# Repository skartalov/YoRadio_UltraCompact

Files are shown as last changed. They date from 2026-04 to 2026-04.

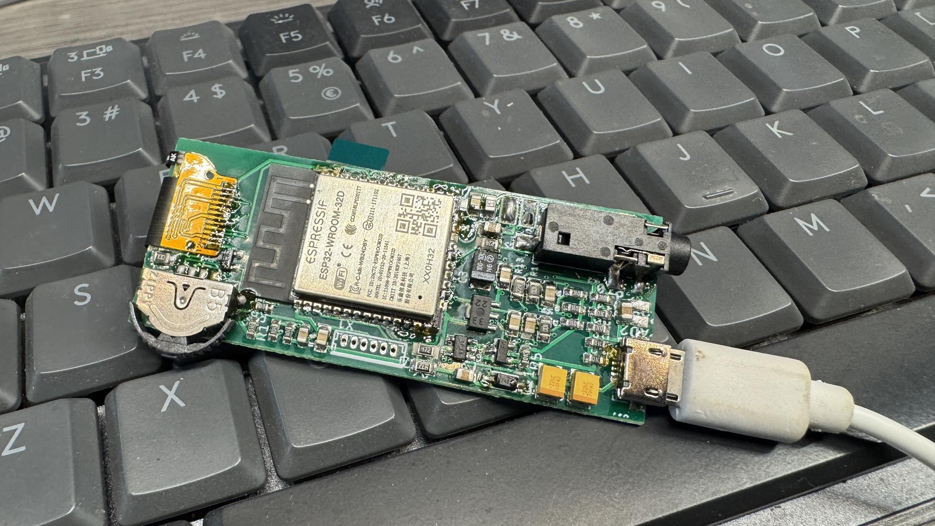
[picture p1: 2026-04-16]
674242527_10164483020409432_1686552852439329188_n.jpg

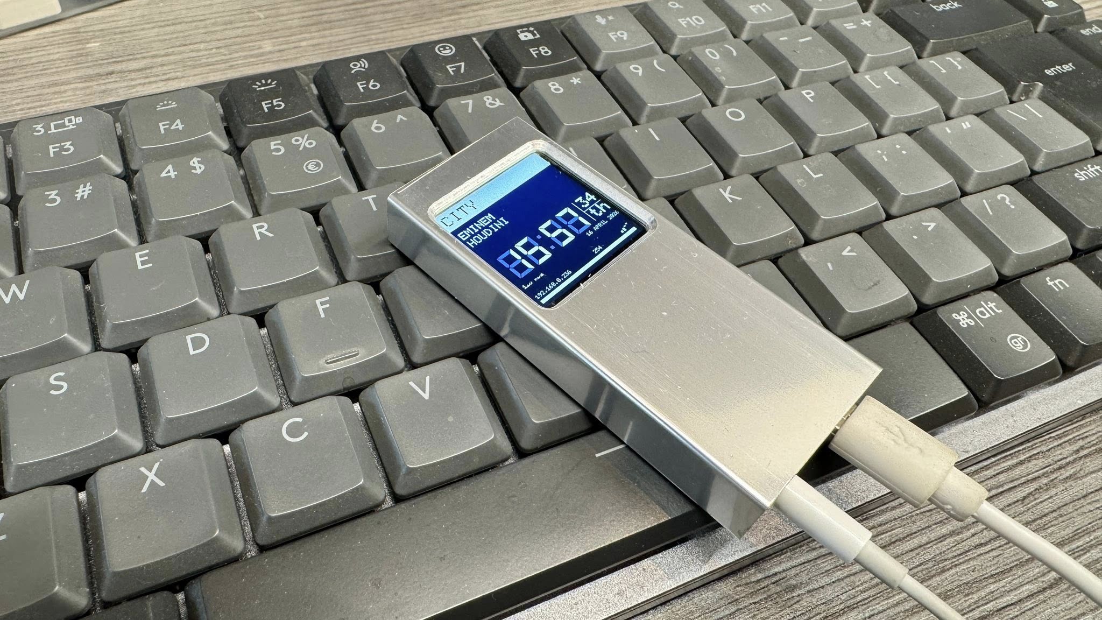
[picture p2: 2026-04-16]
670423982_10164483007904432_1156673706397125330_n.jpg

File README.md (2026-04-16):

This is custom project for YoRadio using 240x240 display, UDA1334 I2S stereo DAC, Li-Po battery charger, 3 way slide button.

Open the schematic and the board with EaglePCB.

Included are: myoptions.h for this specific board and some nice internet radios in playlist.csv

Use this on your own risk, no any support is included. Please don't ask questions. If you know what you are doing you will be able to build this project by your own. If you have questions - this project is not for you.

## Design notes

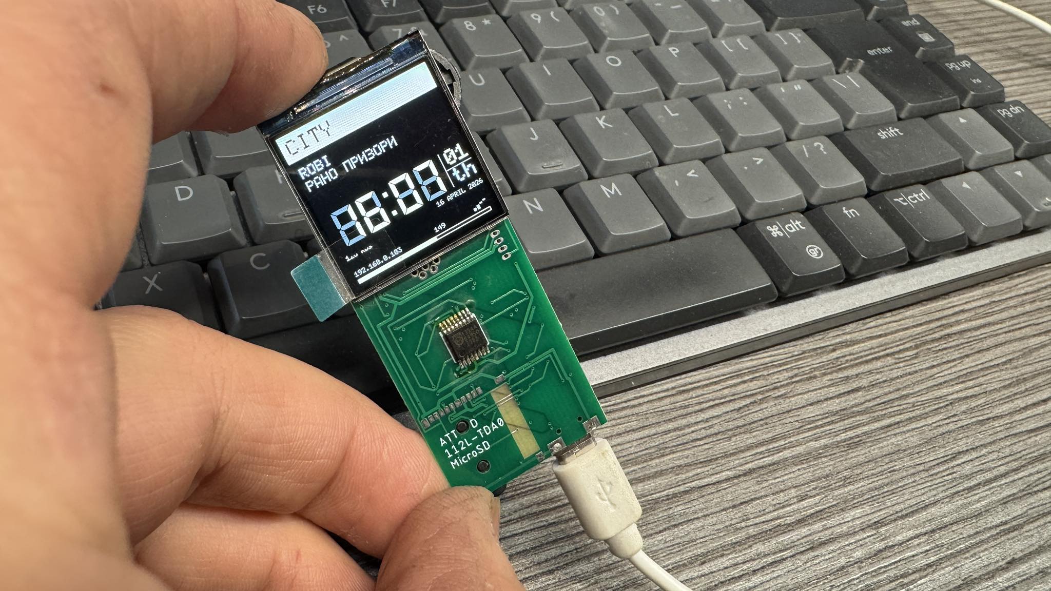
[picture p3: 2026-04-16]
673046234_10164483020429432_1007619045158390353_n.jpg

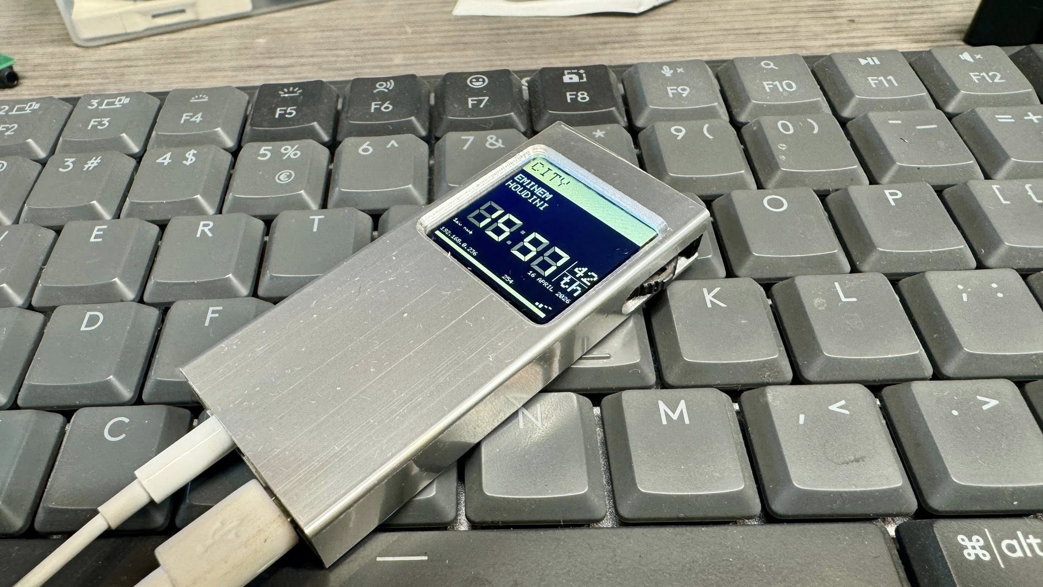
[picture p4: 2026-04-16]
670492199_10164483007809432_5799651930195477875_n.jpg

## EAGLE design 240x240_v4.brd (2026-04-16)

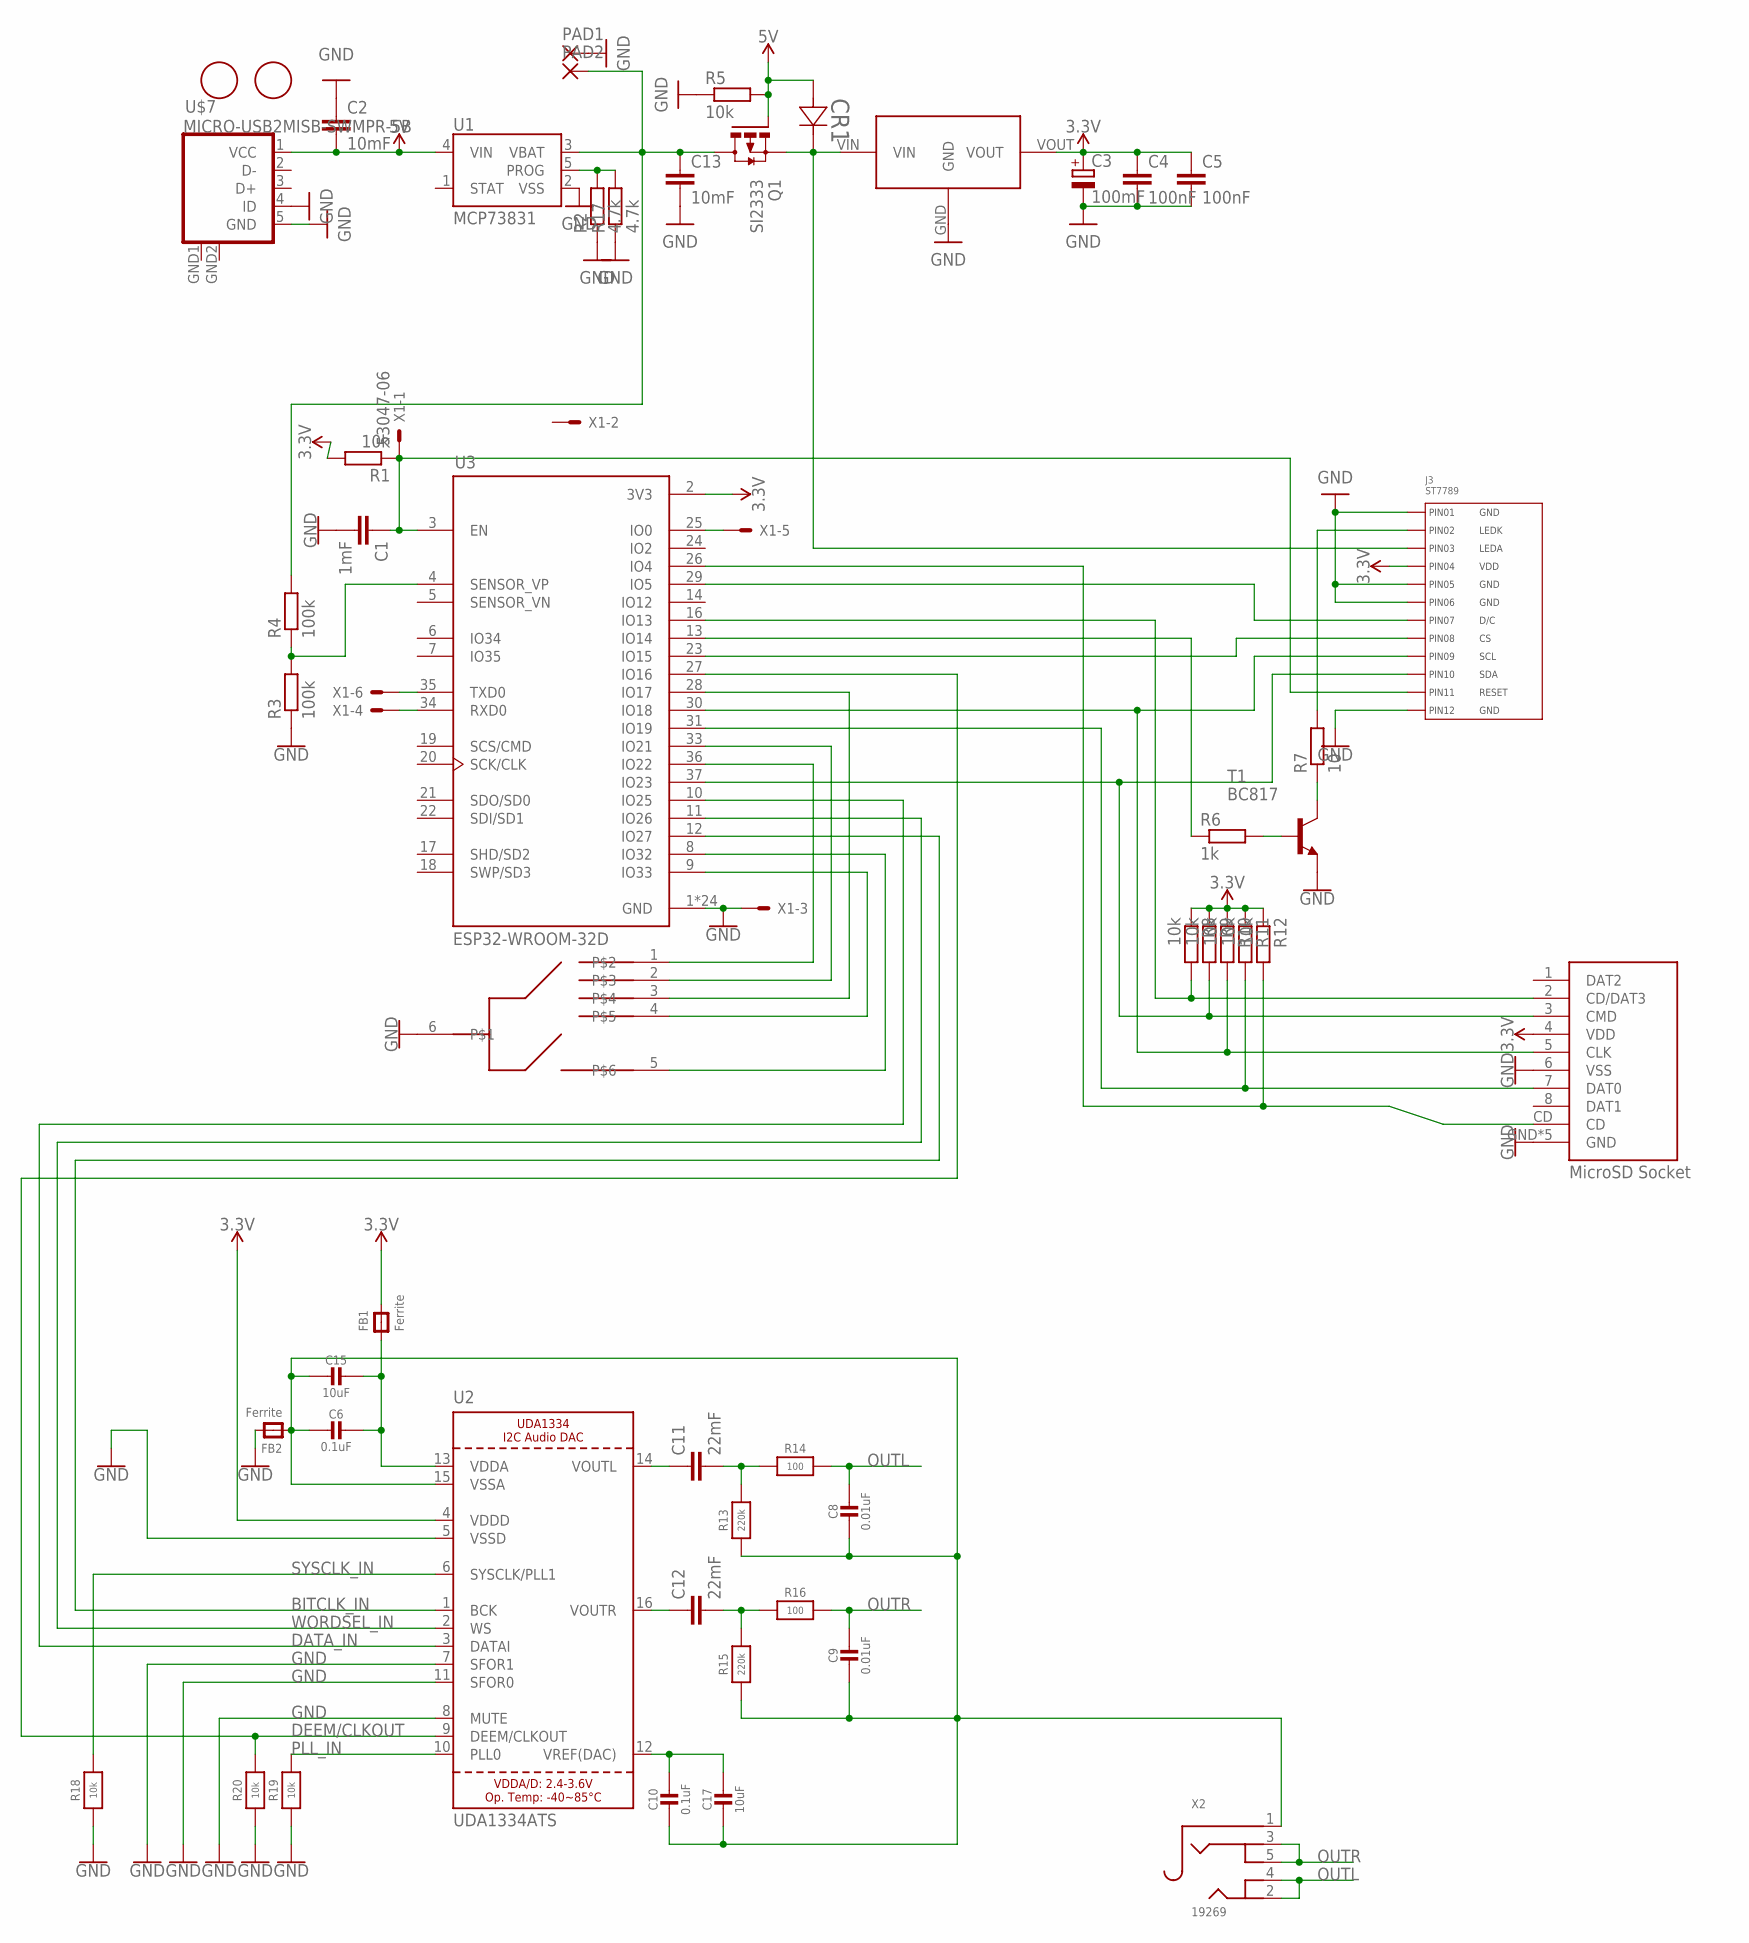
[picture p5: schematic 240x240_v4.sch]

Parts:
C1: 1mF; C0603
C2, C13: 10mF; C0603
C3: 100mF; SMC_B
C4, C5: 100nF; C0805K
C6, C10: 0.1uF; 0805-NO
C8, C9: 0.01uF; 0805-NO
C11, C12: 22mF; C1210
C15, C17: 10uF; 0805-NO
CR1: BAT48; SOD-123_STM-M
FB1, FB2: Ferrite; 0805
J3: ST7789; ST7789_CONNECTOR
PAD1, PAD2: SMD2; SMD1,27-2,54
Q1: SI2333; SUPER-SOT3
R1, R5, R8, R9, R10, R11, R12: 10k; R0603
R2, R17: 4.7k; R0805
R3, R4: 100k; R0603
R6: 1k; R0603
R7: 10; R0805
R13, R15: 220k; 0805-NO
R14, R16: 100; 0805-NO
R18, R19, R20: 10k; 0603-NO
T1: BC817; SOT23-BEC
U1: MCP73831; SOT23-5
U2: UDA1334ATS; SSOP16_4.4MM
U3: ESP32-WROOM-32D; MODULE_ESP32-WROOM-32D
U$1: XC6203; SOT89
U$2: B5-P5S-0D; B5-P5S-0D-Z
U$3, U$4: FIDUCIAL; FIDUCIAL_1MM
U$5: ATTEND_MICROSD_SOCKET
U$7: MICRO-USB2MISB-SWMPR-5B; MICRO-USB2
X1: 53047-06
X2: 19269; 4UCONN_19269

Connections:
3.3V: C3.+, C4.1, C5.1, FB1.2, J3.P$4 (4), R1.2, R8.1, R9.1, R10.1, R11.1, R12.1, U2.4 (VDDD), U3.2 (3V3), U$1.VOUT, U$5.4 (VDD)
5V: C2.2, CR1.1, Q1.1 (G), R5.2, U1.4 (VIN), U$7.1 (VCC)
BITCLK_IN: U2.1 (BCK), U3.12 (IO27)
DATA_IN: U2.3 (DATAI), U3.10 (IO25)
DEEM/CLKOUT: R20.2, U2.9 (DEEM/CLKOUT), U3.27 (IO16)
GND: C1.2, C2.1, C3.-, C4.2, C5.2, C13.2, FB2.2, J3.P$1 (1), J3.P$5 (5), J3.P$6 (6), J3.P$12 (12), PAD1.1, R2.1, R3.1, R5.1, R17.1, R18.1, R19.1, R20.1, T1.E, U1.2 (VSS), U2.5 (VSSD), U2.7 (SFOR1), U2.8 (MUTE), U2.11 (SFOR0), U3.1 (GND), U3.15 (GND), U3.38 (GND), U3.39_1 (GND), U3.39_2 (GND), U3.39_3 (GND), U3.39_4 (GND), U3.39_5 (GND), U3.39_6 (GND), U3.39_7 (GND), U3.39_8 (GND), U3.39_9 (GND), U3.39_10 (GND), U3.39_11 (GND), U3.39_12 (GND), U3.39_13 (GND), U3.39_14 (GND), U3.39_15 (GND), U3.39_16 (GND), U3.39_17 (GND), U3.39_18 (GND), U3.39_19 (GND), U3.39_20 (GND), U3.39_21 (GND), U$1.GND, U$2.6, U$5.6 (VSS), U$5.GND, U$5.GND2 (GND), U$5.GND3 (GND), U$5.GND4 (GND), U$5.GND5 (GND), U$7.4 (ID), U$7.5 (GND), U$7.GND1 (GND), U$7.GND2 (GND), X1.3
unnamed: C1.1, J3.P$11 (11), R1.1, U3.3 (EN), X1.1
unnamed: J3.P$9 (9), R10.2, U3.30 (IO18), U$5.5 (CLK)
unnamed: J3.P$10 (10), R9.2, U3.37 (IO23), U$5.3 (CMD)
unnamed: J3.P$7 (7), U3.29 (IO5)
unnamed: J3.P$8 (8), U3.23 (IO15)
unnamed: U3.35 (TXD0), X1.6
unnamed: U3.34 (RXD0), X1.4
unnamed: R3.2, R4.1, U3.4 (SENSOR_VP)
unnamed: R6.2, T1.B
unnamed: U3.36 (IO22), U$2.1
unnamed: R2.2, R17.2, U1.5 (PROG)
unnamed: J3.P$2 (2), R7.2
unnamed: U3.33 (IO21), U$2.2
unnamed: U3.28 (IO17), U$2.3
unnamed: U3.9 (IO33), U$2.4
unnamed: U3.8 (IO32), U$2.5
unnamed: R11.2, U3.31 (IO19), U$5.7 (DAT0)
unnamed: C13.1, PAD2.1, Q1.3 (D), R4.2, U1.3 (VBAT)
unnamed: U3.25 (IO0), X1.5
unnamed: R7.1, T1.C
unnamed: R6.1, U3.13 (IO14)
unnamed: R8.2, U3.16 (IO13), U$5.2 (CD/DAT3)
unnamed: R12.2, U3.26 (IO4), U$5.CD
unnamed: C6.1, C15.1, FB1.1, U2.13 (VDDA)
unnamed: C11.2, R13.2, R14.1
unnamed: C12.2, R15.2, R16.1
unnamed: C10.1, C17.1, U2.12 (VREF(DAC))
unnamed: C12.1, U2.16 (VOUTR)
unnamed: C11.1, U2.14 (VOUTL)
unnamed: CR1.2, J3.P$3 (3), Q1.2 (S), U$1.VIN
unnamed: C6.2, C8.2, C9.2, C10.2, C15.2, C17.2, FB2.1, R13.1, R15.1, U2.15 (VSSA), X2.1
OUTL: C8.1, R14.2, X2.2, X2.4
OUTR: C9.1, R16.2, X2.3, X2.5
PLL_IN: R19.2, U2.10 (PLL0)
SYSCLK_IN: R18.2, U2.6 (SYSCLK/PLL1)
WORDSEL_IN: U2.2 (WS), U3.11 (IO26)

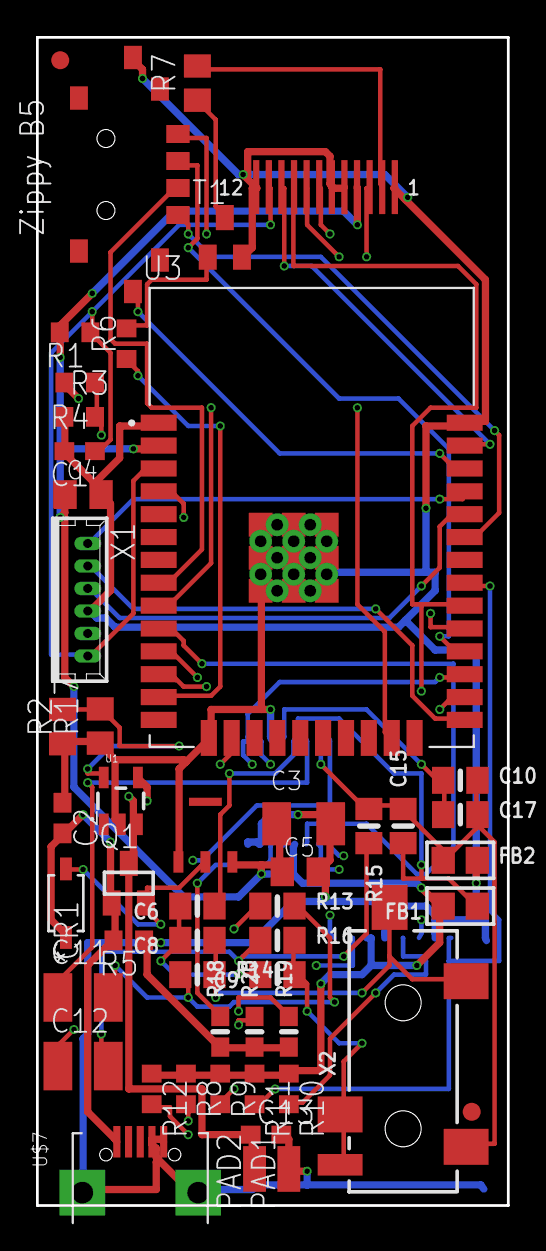
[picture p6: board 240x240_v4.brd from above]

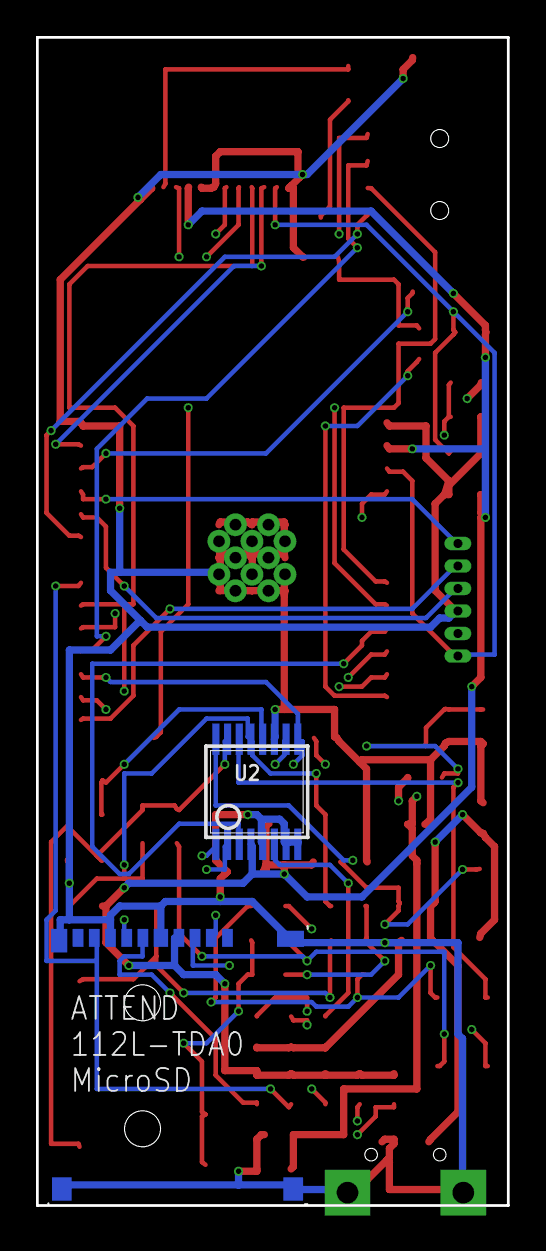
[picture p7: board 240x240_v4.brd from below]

Board: 4 copper layers, 26.2 x 64.9 mm, 53 parts (2 on the bottom side), 42 nets.

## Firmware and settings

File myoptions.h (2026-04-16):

#ifndef myoptions_h
#define myoptions_h

/*******************************************************

Copy this file in the project root directory (next to the yoRadio.ino file)
Uncomment the lines you need, to override the default value and set the values according to the connected equipment.

The connection tables are located here https://github.com/e2002/yoradio#connection-tables

********************************************************/
//#define LED_BUILTIN     255               /*  Onboard LED Pin (turn OFF by default) */
//#define LED_INVERT      false             /*  Invert Onboard LED? */
#define L10N_LANGUAGE     EN                /*  Language (EN, RU). More info in yoRadio/locale/displayL10n_(en|ru).h  */

/*  DSP_MODEL. See description/available values in https://github.com/e2002/yoradio/wiki/Available-display-models  */
/*  This option is required. Use DSP_DUMMY if no display is connected */
#define DSP_MODEL         DSP_ST7789_240
/*
 * !!! Important !!!
 * if you use colored TFT displays with the esp32 wroom, due to lack of memory, you must modify the file Arduino/libraries/AsyncTCP/src/AsyncTCP.cpp
 * replace the line 221
 * xTaskCreateUniversal(_async_service_task, "async_tcp", 8192 * 2, NULL, 3, &_async_service_task_handle, CONFIG_ASYNC_TCP_RUNNING_CORE);
 * with
 * xTaskCreateUniversal(_async_service_task, "async_tcp", 8192 / 2, NULL, 3, &_async_service_task_handle, CONFIG_ASYNC_TCP_RUNNING_CORE);
*/
/******************************************/

/*  VSPI PINS. SCL(SCK, CLK) must be connected to pin 18
               SDA(MOSI, DIN, SDI) must be connected to pin 23  
               for ESP32-S3 see ESP32-S3 Pin Reference http://wiki.fluidnc.com/en/hardware/ESP32-S3_Pin_Reference*/
               
#define TFT_CS            15                 /*  SPI CS pin  */
#define TFT_RST           -1                /*  SPI RST pin.  set to -1 and connect to Esp EN pin */
#define TFT_DC            5                 /*  SPI DC/RS pin  */
/*  HSPI PINS. SCL(SCK, CLK) must be connected to pin 14
               SDA(MOSI, DIN, SDI) must be connected to pin 13  */
//#define DSP_HSPI          false             /*  Use HSPI for display  */
/******************************************/

/*  NEXTION  */
//#define NEXTION_RX    255                   /*  Nextion RX pin  */
//#define NEXTION_TX    255                   /*  Nextion TX pin  */
  
/*  I2C PINS  */
//#define I2C_SDA           21                /*  I2C SDA pin. It is best to connect to pin 21.  */
//#define I2C_SCL           22                /*  I2C SCL pin. It is best to connect to pin 22.  */
//#define I2C_RST           -1                /*  I2C RST pin. Set to -1 if not used  */

/*        I2S DAC                 */
#define I2S_DOUT          25                /*  DIN connection. Should be set to 255 if the board is not used */
#define I2S_BCLK          27                /*  BCLK Bit clock */
#define I2S_LRC           26                /*  WSEL Left Right Clock */
/******************************************/

/*  VS1053 VSPI PINS. VS1053 SCK must be connected to pin 18
                      VS1053 MISO must be connected to pin 19
                      VS1053 MOSI must be connected to pin 23  */
//#define VS1053_CS         255               /*  XCS pin. Should be set to 255 if the board is not used */
//#define VS1053_DCS        25                /*  XDCS pin.  */
//#define VS1053_DREQ       26                /*  DREQ pin.  */
//#define VS1053_RST        -1                /*  XRESET pin. Set to -1 if connected to Esp EN pin */
/*  VS1053 HSPI PINS. VS1053 SCK must be connected to pin 14
                      VS1053 MISO must be connected to pin 12
                      VS1053 MOSI must be connected to pin 13  */
//#define VS_HSPI           false             /*  Use HSPI for VS  */
/******************************************/

/*  ENCODER  */
//#define ENC_BTNL              255           /*  Left rotation */
//#define ENC_BTNB              255           /*  Encoder button */
//#define ENC_BTNR              255           /*  Right rotation */
//#define ENC_INTERNALPULLUP    true          /*  Enable the weak pull up resistors */
//#define ENC_HALFQUARD         true          /*  Experiment  with it */
/******************************************/

/*  SDCARD  */
/*  MISO is the same as D0, MOSI is the same as D1 */
/*  SD VSPI PINS. SD SCK must be connected to pin 18
                  SD MISO must be connected to pin 19
                  SD MOSI must be connected to pin 23  */
/*  SD HSPI PINS. SD SCK must be connected to pin 14
                  SD MISO must be connected to pin 12
                  SD MOSI must be connected to pin 13  */
#define SDC_CS                 4           /* SDCARD CS pin */
//#define SD_HSPI                false         /* use HSPI for SD (miso=12, mosi=13, clk=14) instead of VSPI (by default) */

/*        RTC                     */
//#define RTC_MODULE            RTC_MODULE_UNDEFINED  /*  one of DS3231, DS1307, RTC_MODULE_UNDEFINED(default)  */
//#define RTC_SDA               255            /* RTC_SDA */
//#define RTC_SCL               255            /* RTC_SCL */

/*  ENCODER2  */
//#define ENC2_BTNL              255           /*  Left rotation */
//#define ENC2_BTNB              255           /*  Encoder button */
//#define ENC2_BTNR              255           /*  Right rotation */
//#define ENC2_INTERNALPULLUP    true          /*  Enable the weak pull up resistors */
//#define ENC2_HALFQUARD         false         /*  (true, false, 255) Experiment  with it */
/******************************************/

/*  BUTTONS  */
#define BTN_LEFT              21           /*  VolDown, Prev */
#define BTN_CENTER            32           /*  Play, Stop, Show playlist */
#define BTN_RIGHT             17           /*  VolUp, Next */
//#define BTN_UP                22           /*  Prev, Move Up */
//#define BTN_DOWN              33           /*  Next, Move Down */
//#define BTN_INTERNALPULLUP    true          /*  Enable the weak pull up resistors */
//#define BTN_LONGPRESS_LOOP_DELAY    200     /*  Delay between calling DuringLongPress event */
//#define BTN_CLICK_TICKS    300              /*  Event Timing https://github.com/mathertel/OneButton#event-timing */
//#define BTN_PRESS_TICKS    500              /*  Event Timing https://github.com/mathertel/OneButton#event-timing */
//#define BTN_MODE            32           /*  MODE switcher  */
/******************************************/

/*  LCD DISPLAY 1602  */
//#define LCD_RS                255           /*  RS Pin */
//#define LCD_E                 255           /*  E Pin  */
//#define LCD_D4                255           /*  D4 Pin */
//#define LCD_D5                255           /*  D5 Pin */
//#define LCD_D6                255           /*  D6 Pin */
//#define LCD_D7                255           /*  D7 Pin */
/******************************************/
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

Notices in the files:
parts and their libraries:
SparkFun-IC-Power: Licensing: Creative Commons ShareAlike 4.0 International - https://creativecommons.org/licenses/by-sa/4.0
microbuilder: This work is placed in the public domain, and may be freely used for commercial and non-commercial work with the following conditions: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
